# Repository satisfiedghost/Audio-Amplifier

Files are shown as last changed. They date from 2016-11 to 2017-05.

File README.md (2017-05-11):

# Audio-Amplifier
A simple audio amplifier, intended to drive larger (>25Ω) headphones.

# ToDo
I ran into some bypassing issues with the first board revision. 0.1uF caps need to be added directly to the power supplies
of U1 and U2. Additinally, U1 should have an in-loop compensation circuit added to ease driving the capacitive load.
Some footprints are too large, and could be spaced more closely.

# Notes
I chose Polypropylene as the material for my input capacitor, as they tend to have a lower distortion than others, at the
expense of a larger form factor. 0.47uF lowered the -3dB point to 3Hz, which should exhibit acceptable filtering once
the minimum range of human hearing is reached.

The 1000uF electrolytic on the power supply is likely overkill, but it certainly doesn't hurt to have if the headphones 
end up drawing large current spikes during loud parts of songs.

Some research told me that the OPA213PA op-amp is perfectly acceptable unless you're a true audiophile, in which case
a more expensive solution might be warranted.

The three bypass caps on each +- power supply are absolutey necessary, the amplifier will distort horribly without them.

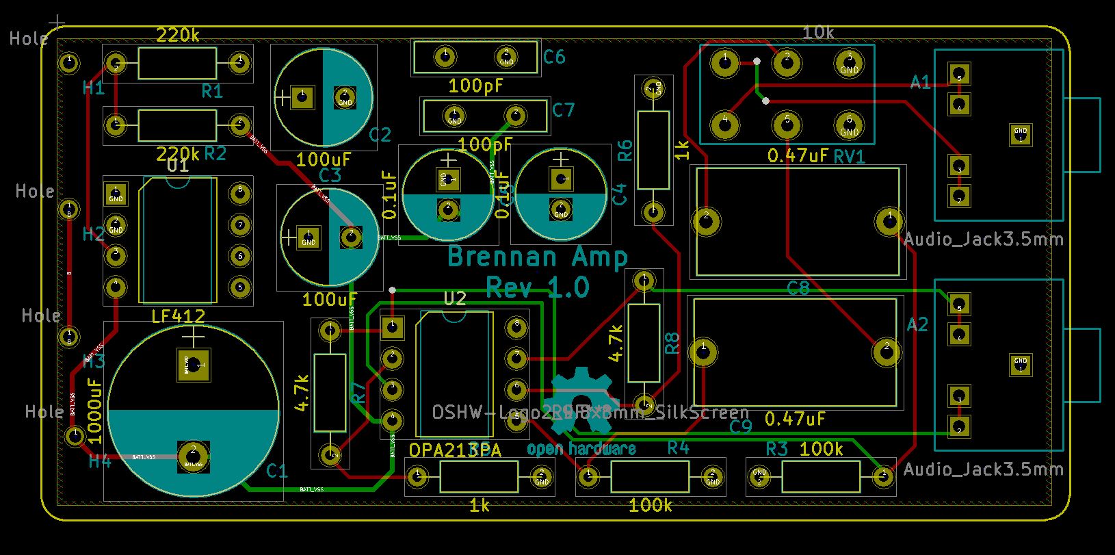
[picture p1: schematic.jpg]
Schematic


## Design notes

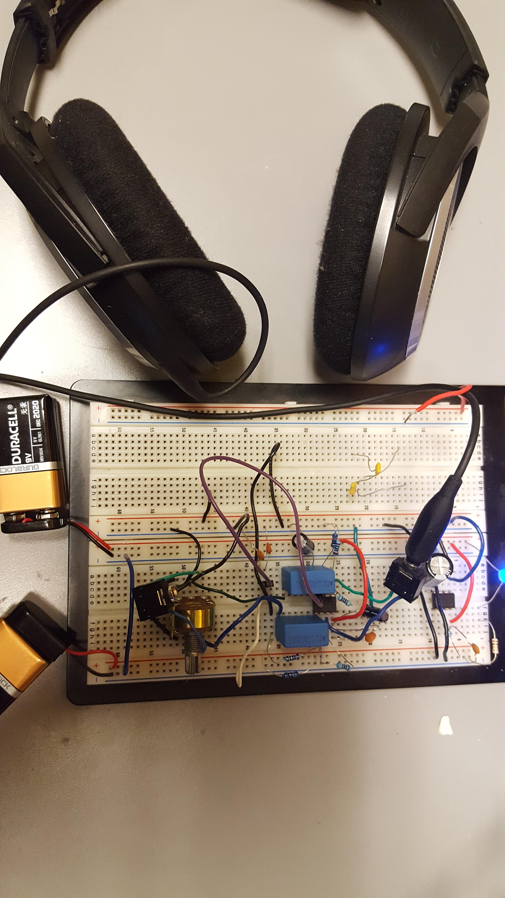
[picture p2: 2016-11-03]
amplifier.jpg

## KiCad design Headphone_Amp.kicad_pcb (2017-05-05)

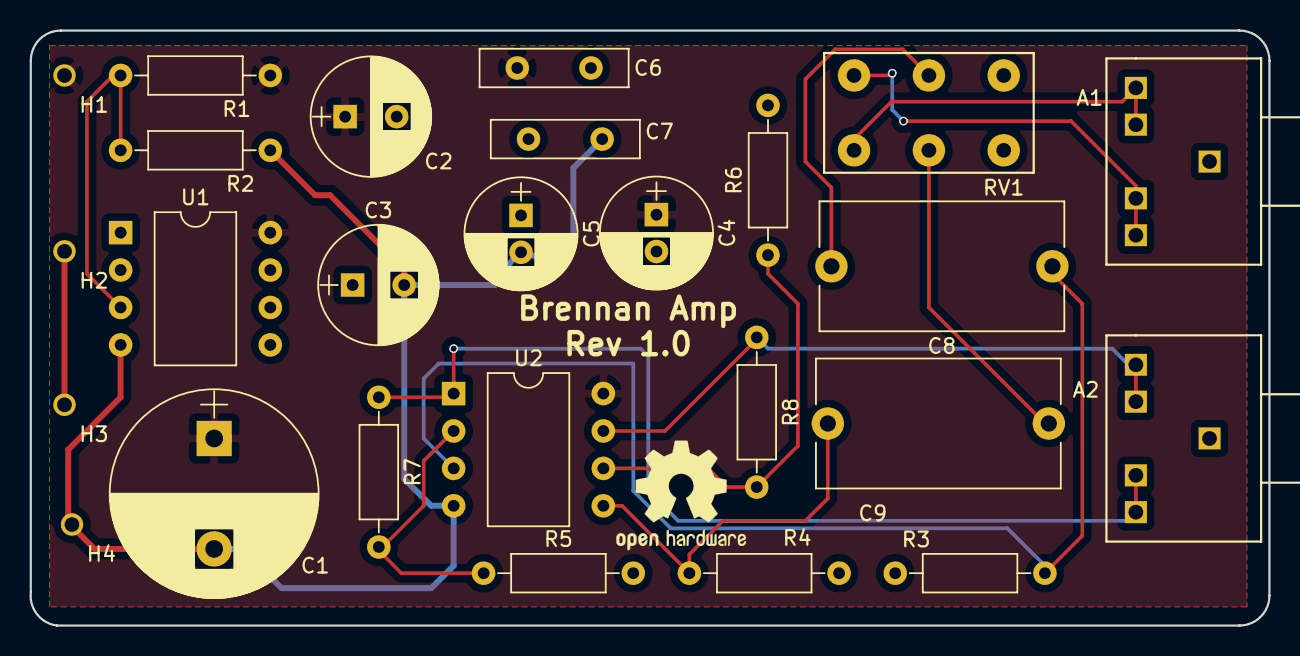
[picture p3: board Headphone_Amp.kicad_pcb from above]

Board: 2 copper layers, 84.1 x 40.4 mm, 26 parts (0 on the bottom side), 15 nets.

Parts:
A1, A2: Audio_Jack3.5mm
C1: 1000uF; CP_Radial_D14.0mm_P7.50mm
C2, C3: 100uF; CP_Radial_D8.0mm_P3.50mm
C4, C5: 0.1uF; CP_Radial_D7.5mm_P2.50mm
C6, C7: 100pF; C_Disc_D10.0mm_W2.5mm_P5.00mm
C8, C9: 0.47uF; C_Rect_L16.5mm_W8.7mm_P15.00mm_MKT
H1, H2, H3, H4: Hole
R1, R2: 220k; R_Axial_DIN0207_L6.3mm_D2.5mm_P10.16mm_Horizontal
R3, R4: 100k; R_Axial_DIN0207_L6.3mm_D2.5mm_P10.16mm_Horizontal
R5, R6: 1k; R_Axial_DIN0207_L6.3mm_D2.5mm_P10.16mm_Horizontal
R7, R8: 4.7k; R_Axial_DIN0207_L6.3mm_D2.5mm_P10.16mm_Horizontal
RV1: 10k; DualGanged_POT
U1: LF412; DIP-8_W10.16mm
U2: OPA213PA; DIP-8_W10.16mm

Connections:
B: H2.1, H3.1
BATT_VDD: C1.1, C2.1, C4.1, C6.1, H1.1, R1.1, U1.8, U2.8
BATT_VSS: C1.2, C3.2, C5.2, C7.2, H4.1, R2.2, U1.4, U2.4
GND: A1.1, A2.1, C2.2, C3.1, C4.2, C5.1, C6.2, C7.1, R3.2, R4.2, R5.2, R6.2, RV1.3, RV1.6, U1.1, U1.2
unnamed: A1.2, A1.3, RV1.1
unnamed: A1.4, A1.5, RV1.4
unnamed: A2.2, A2.3, R7.1, U2.1
unnamed: A2.4, A2.5, R8.1, U2.7
unnamed: C8.1, R3.1, U2.3
unnamed: C8.2, RV1.2
unnamed: C9.1, R4.1, U2.5
unnamed: C9.2, RV1.5
unnamed: R1.2, R2.1, U1.3
unnamed: R5.1, R7.2, U2.2
unnamed: R6.1, R8.2, U2.6

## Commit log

2017-05-05 KiCad Files
    [Headphone_Amp.kicad_pcb, Headphone_Amp.sch]
2017-05-05 Schematic image
2017-05-11 potentiometer footprint
2017-05-11 through hole footprint
